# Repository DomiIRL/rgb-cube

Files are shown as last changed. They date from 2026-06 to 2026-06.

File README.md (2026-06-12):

# RGB Cube

A **6×6×6 RGB LED matrix cube** (216 WS2812B-compatible LEDs) that plays 3D
animations, driven by an ESP32. Firmware, 3D-printable parts, and build notes
all live in this repo.

> Built for the **"Rechnerarchitektur"** class at **Nordakademie**.

> [!WARNING]
> **The firmware is heavily "vibecoded."**
> Almost all of my time on this project went into the *physical* build —
> soldering 216 LEDs, printing jigs, bending legs, and wiring the cube took
> *really* long. To actually get animations running on the finished cube, the
> ESP32 code in [`code/`](code/) was written largely with AI assistance. It
> works on the real hardware, but don't read it as a model of clean,
> hand-crafted embedded C++.

## Hardware

| | |
|---|---|
| **LEDs** | 8 mm through-hole RGB, integrated WS2812B-compatible controller |
| **Grid** | 6 × 6 × 6 = 216 LEDs, 25 mm pitch, ~125 mm cube |
| **Wiring** | Single-wire WS2812B serpentine daisy-chain |
| **MCU** | ESP32 DevKit V1 (data on GPIO 14, mode button on GPIO 34) |
| **Power** | USB-C PD board (~5 A @ 5 V) |

Full geometry, electronics and enclosure specs: [`CLAUDE.md`](CLAUDE.md).

## Repository layout

```
rgb-cube/
├── code/      ESP32 firmware (PlatformIO)
├── models/    3D-printable parts (OpenSCAD sources + STLs + previews)
├── docs/      design notes (plans / specs)
├── BUILD.md   firmware build & dev guide
└── CLAUDE.md  hardware / geometry / model reference
```

## Firmware — [`code/`](code/)

PlatformIO project (`esp32dev` env, Arduino framework, Adafruit NeoPixel).
A hardware button cycles through animation modes; the active mode is persisted
in NVS across reboots.

**Build & flash** (easiest via the VSCode PlatformIO extension):

```bash
cd code
pio run -e esp32dev            # build
pio run -e esp32dev -t upload  # flash
```

See [`BUILD.md`](BUILD.md) for the Cube/Mode API and how to add a mode.

## 3D models — [`models/`](models/)

OpenSCAD sources with exported STLs and a render preview, one folder per part.
Printed on a Bambu Lab A1 Mini in PLA.

| Folder | Part |
|---|---|
| [`layer_jig/`](models/layer_jig/) | Soldering jig — holds one 6×6 LED layer flat while soldering |
| [`electronics_enclosure/`](models/electronics_enclosure/) | Base enclosure (body + lid) that hides the ESP32 and PD board; the cube sits on top |
| [`led_pin_bender/`](models/led_pin_bender/) | Tool to bend LED legs to a consistent shape |
| [`tests/`](models/tests/) | Throwaway calibration prints (LED hole fit, standoff fit) |

## Status

The cube is built and running animations. Open items (firmware tuning, final
wiring scheme) are tracked at the bottom of [`CLAUDE.md`](CLAUDE.md).

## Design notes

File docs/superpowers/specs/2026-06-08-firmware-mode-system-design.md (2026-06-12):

# Firmware Mode System — Design Spec
_2026-06-08_

## Goal

Provide a clean OOP firmware architecture for the 6×6×6 LED cube that:
- Addresses LEDs by (x, y, z) coordinates instead of raw index
- Supports multiple display modes, each encapsulated in its own class
- Allows mode switching via a button (hardcoded index for now, ISR later)

---

## Architecture

### Cube

Owns the `Adafruit_NeoPixel` strip. All LED writes go through it.

**Public API:**
- `begin()` — initialise strip
- `clear()` — zero all pixels
- `show()` — flush to hardware
- `setBrightness(uint8_t)`
- `setPixel(int x, int y, int z, uint8_t r, uint8_t g, uint8_t b)`
- `setPixel(int x, int y, int z, uint32_t color)`
- `static uint32_t colorRGB(uint8_t r, uint8_t g, uint8_t b)`
- `static uint32_t colorHSV(uint16_t hue, uint8_t sat, uint8_t val)`

**coordToIndex** is a private static method — single place to update when wiring scheme is finalised.  
Current mapping: `index = z * 36 + y * 6 + x` (layer-major, row-major, left-to-right).  
Out-of-bounds coordinates are silently ignored (return -1).

Constants `CUBE_SIZE = 6` and `CUBE_LEDS = 216` are defined in `Cube.h`.

---

### Mode (abstract base)

```cpp
class Mode {
public:
    virtual ~Mode() = default;
    virtual void update(Cube& cube, uint32_t ms) = 0;
    virtual void onEnter(Cube& cube) { cube.clear(); }
    virtual void onExit(Cube& cube) {}
};
```

`update()` is called every loop iteration. `ms` is `millis()` — modes use it for non-blocking animation timing. No `delay()` in any mode.

---

### ModeSolid

Sets all LEDs to a single color. Color is passed as a constructor argument.

```cpp
ModeSolid(uint8_t r, uint8_t g, uint8_t b);
```

`update()` only redraws on first call after `onEnter` to avoid redundant strip writes.

---

### main.cpp

```cpp
#define CURRENT_MODE 0   // change to switch mode; button will replace this

Mode* modes[] = { &modeSolid /*, &modeRainbow, ... */ };
constexpr int NUM_MODES = sizeof(modes) / sizeof(modes[0]);
int modeIndex = CURRENT_MODE;
```

Button ISR (future): increment `modeIndex % NUM_MODES`, call `modes[modeIndex-1]->onExit()`, call `modes[modeIndex]->onEnter()`.

---

## File Layout

```
src/
  main.cpp
  Cube.h
  Cube.cpp
  Mode.h
  modes/
    ModeSolid.h
    ModeSolid.cpp
```

Existing `test.cpp` cleared. `log.cpp` left empty.

---

## Constraints

- NEO_RGB color order (confirmed from hardware testing)
- Data pin: GPIO 4
- `coordToIndex` must be updated once wiring scheme is decided (CLAUDE.md: snake vs straight)
- Testing with 2 physical LEDs — code uses full 216-LED buffer; only first 2 respond

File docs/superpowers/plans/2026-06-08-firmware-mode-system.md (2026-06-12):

# Firmware Mode System Implementation Plan

> **For agentic workers:** REQUIRED SUB-SKILL: Use superpowers:subagent-driven-development (recommended) or superpowers:executing-plans to implement this plan task-by-task. Steps use checkbox (`- [ ]`) syntax for tracking.

**Goal:** Replace the ad-hoc test sketch with a clean OOP firmware: a `Cube` class for coordinate-based LED control, an abstract `Mode` base, and a `ModeSolid` mode — all wired together in `main.cpp` with a hardcoded mode selector ready for a button.

**Architecture:** `Cube` owns the `Adafruit_NeoPixel` strip and maps (x,y,z) → strip index through a single private method. `Mode` is a pure-virtual base; each mode class implements `update(Cube&, uint32_t ms)`. `main.cpp` holds a pointer array of modes and an index; switching a mode calls `onExit`/`onEnter` and re-points `currentMode`.

**Tech Stack:** ESP32 DevKit V1, PlatformIO + Arduino framework, Adafruit NeoPixel library, NEO_RGB color order, GPIO 4 data pin.

> **Note:** No unit test framework is available for embedded targets. Verification steps use `pio run` (compile check) and flash + serial monitor (behavioral check).

---

## File Map

| Action | Path | Responsibility |
|---|---|---|
| Create | `src/Cube.h` | Constants, Cube class declaration |
| Create | `src/Cube.cpp` | Cube implementation + coordToIndex |
| Create | `src/Mode.h` | Abstract Mode base class |
| Create | `src/modes/ModeSolid.h` | ModeSolid declaration |
| Create | `src/modes/ModeSolid.cpp` | ModeSolid implementation |
| Overwrite | `src/main.cpp` | Entry point, mode array, loop |
| Clear | `src/test.cpp` | Remove old test sketch (prevents duplicate setup/loop) |

---

### Task 1: Cube class

**Files:**
- Create: `src/Cube.h`
- Create: `src/Cube.cpp`

- [ ] **Step 1: Create `src/Cube.h`**

```cpp
#pragma once
#include <Adafruit_NeoPixel.h>

static constexpr uint8_t  CUBE_SIZE = 6;
static constexpr uint16_t CUBE_LEDS = CUBE_SIZE * CUBE_SIZE * CUBE_SIZE;

class Cube {
public:
    explicit Cube(uint8_t pin);
    void begin();
    void clear();
    void show();
    void setBrightness(uint8_t brightness);
    void setPixel(int x, int y, int z, uint8_t r, uint8_t g, uint8_t b);
    void setPixel(int x, int y, int z, uint32_t color);
    static uint32_t colorRGB(uint8_t r, uint8_t g, uint8_t b);
    static uint32_t colorHSV(uint16_t hue, uint8_t sat = 255, uint8_t val = 255);

private:
    Adafruit_NeoPixel _strip;
    static int coordToIndex(int x, int y, int z);
};
```

- [ ] **Step 2: Create `src/Cube.cpp`**

```cpp
#include "Cube.h"

Cube::Cube(uint8_t pin)
    : _strip(CUBE_LEDS, pin, NEO_RGB + NEO_KHZ800) {}

void Cube::begin()                    { _strip.begin(); _strip.show(); }
void Cube::clear()                    { _strip.clear(); }
void Cube::show()                     { _strip.show(); }
void Cube::setBrightness(uint8_t b)   { _strip.setBrightness(b); }

void Cube::setPixel(int x, int y, int z, uint8_t r, uint8_t g, uint8_t b) {
    int idx = coordToIndex(x, y, z);
    if (idx >= 0) _strip.setPixelColor(idx, r, g, b);
}

void Cube::setPixel(int x, int y, int z, uint32_t color) {
    int idx = coordToIndex(x, y, z);
    if (idx >= 0) _strip.setPixelColor(idx, color);
}

uint32_t Cube::colorRGB(uint8_t r, uint8_t g, uint8_t b) {
    return Adafruit_NeoPixel::Color(r, g, b);
}

uint32_t Cube::colorHSV(uint16_t hue, uint8_t sat, uint8_t val) {
    return Adafruit_NeoPixel::ColorHSV(hue, sat, val);
}

// TODO: update this mapping once wiring scheme is decided (snake vs straight)
// Current assumption: layer-major, row-major, left-to-right
// z=0 is bottom layer, x increases left-to-right, y increases front-to-back
int Cube::coordToIndex(int x, int y, int z) {
    if (x < 0 || x >= CUBE_SIZE ||
        y < 0 || y >= CUBE_SIZE ||
        z < 0 || z >= CUBE_SIZE) return -1;
    return z * CUBE_SIZE * CUBE_SIZE + y * CUBE_SIZE + x;
}
```

- [ ] **Step 3: Verify it compiles**

```bash
cd ~/projects/led-cube/code && pio run
```

Expected: `[SUCCESS]` — the Cube files compile but nothing calls them yet (no linker errors since main still exists from test.cpp).

---

### Task 2: Mode base class

**Files:**
- Create: `src/Mode.h`

- [ ] **Step 1: Create `src/Mode.h`**

```cpp
#pragma once
#include "Cube.h"

class Mode {
public:
    virtual ~Mode() = default;
    virtual void update(Cube& cube, uint32_t ms) = 0;
    virtual void onEnter(Cube& cube) { cube.clear(); cube.show(); }
    virtual void onExit(Cube& cube)  {}
};
```

- [ ] **Step 2: Verify it compiles**

```bash
pio run
```

Expected: `[SUCCESS]`

---

### Task 3: ModeSolid

**Files:**
- Create: `src/modes/ModeSolid.h`
- Create: `src/modes/ModeSolid.cpp`

- [ ] **Step 1: Create `src/modes/ModeSolid.h`**

```cpp
#pragma once
#include "../Mode.h"

class ModeSolid : public Mode {
public:
    ModeSolid(uint8_t r, uint8_t g, uint8_t b);
    void update(Cube& cube, uint32_t ms) override;
    void onEnter(Cube& cube) override;

private:
    uint8_t _r, _g, _b;
    bool _drawn;
};
```

- [ ] **Step 2: Create `src/modes/ModeSolid.cpp`**

```cpp
#include "ModeSolid.h"

ModeSolid::ModeSolid(uint8_t r, uint8_t g, uint8_t b)
    : _r(r), _g(g), _b(b), _drawn(false) {}

void ModeSolid::onEnter(Cube& cube) {
    _drawn = false;
    cube.clear();
    cube.show();
}

void ModeSolid::update(Cube& cube, uint32_t ms) {
    if (_drawn) return;
    for (int z = 0; z < CUBE_SIZE; z++)
        for (int y = 0; y < CUBE_SIZE; y++)
            for (int x = 0; x < CUBE_SIZE; x++)
                cube.setPixel(x, y, z, _r, _g, _b);
    cube.show();
    _drawn = true;
}
```

- [ ] **Step 3: Verify it compiles**

```bash
pio run
```

Expected: `[SUCCESS]`

---

### Task 4: Wire up main.cpp

**Files:**
- Overwrite: `src/main.cpp` (create if absent)
- Clear: `src/test.cpp` (must be empty to avoid duplicate `setup`/`loop` linker error)

- [ ] **Step 1: Clear `src/test.cpp`**

Replace the entire content of `src/test.cpp` with an empty file (zero bytes).

- [ ] **Step 2: Write `src/main.cpp`**

```cpp
#include <Arduino.h>
#include "Cube.h"
#include "modes/ModeSolid.h"

#define DATA_PIN     4
#define CURRENT_MODE 0   // 0 = solid red; button will replace this

Cube cube(DATA_PIN);

ModeSolid modeSolid(255, 0, 0);   // red

Mode* modes[] = { &modeSolid };
constexpr int NUM_MODES = sizeof(modes) / sizeof(modes[0]);

int       modeIndex   = CURRENT_MODE;
Mode*     currentMode = modes[CURRENT_MODE];

void setMode(int index) {
    currentMode->onExit(cube);
    modeIndex   = index % NUM_MODES;
    currentMode = modes[modeIndex];
    currentMode->onEnter(cube);
}

void setup() {
    Serial.begin(115200);
    Serial.println("LED Cube boot OK");
    cube.begin();
    cube.setBrightness(50);
    currentMode->onEnter(cube);
}

void loop() {
    currentMode->update(cube, millis());
}
```

- [ ] **Step 3: Build**

```bash
pio run
```

Expected: `[SUCCESS]` with RAM ~6%, Flash ~21%.

- [ ] **Step 4: Flash and verify**

```bash
pio run --target upload && pio device monitor
```

Expected serial output:
```
LED Cube boot OK
```
Expected hardware: LED(s) solid red, not blinking.

---

## Adding more modes later

To add a new mode (e.g. `ModeRainbow`):

1. Create `src/modes/ModeRainbow.h` and `src/modes/ModeRainbow.cpp` following the same pattern as `ModeSolid`.
2. In `main.cpp`: `#include "modes/ModeRainbow.h"`, instantiate `ModeRainbow modeRainbow;`, add `&modeRainbow` to the `modes[]` array.
3. To switch via button: call `setMode((modeIndex + 1) % NUM_MODES)` in the button ISR.

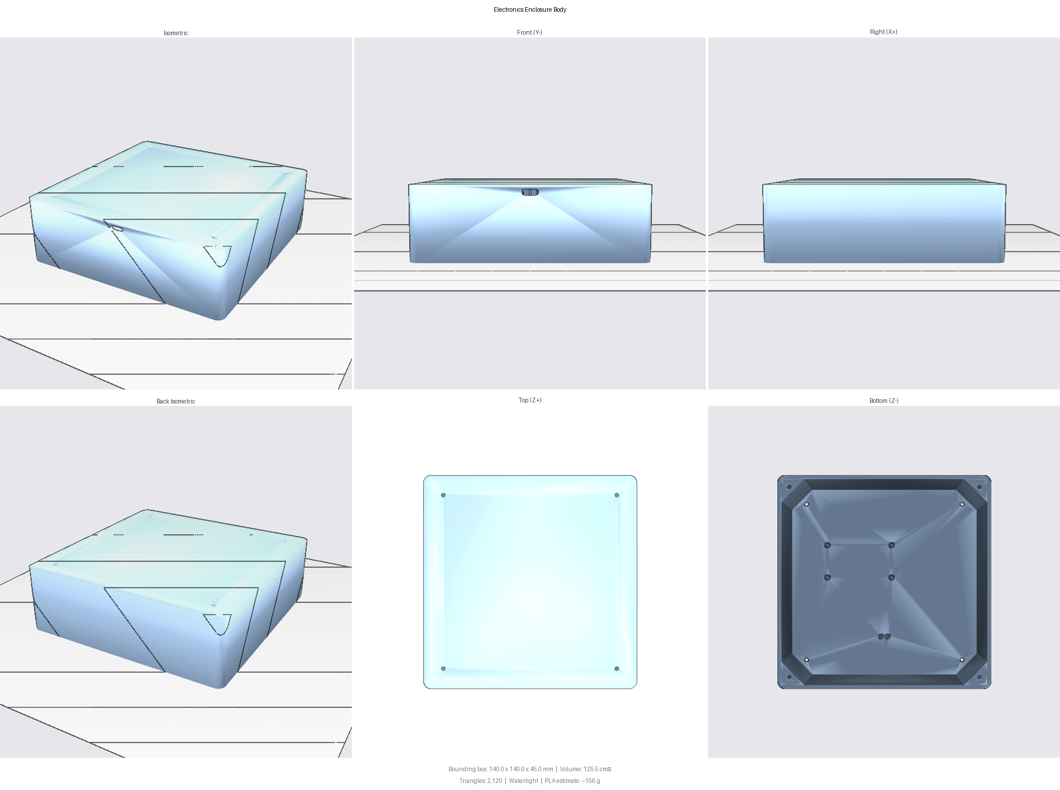
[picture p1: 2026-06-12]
models/electronics_enclosure/electronics_enclosure_body_preview.png

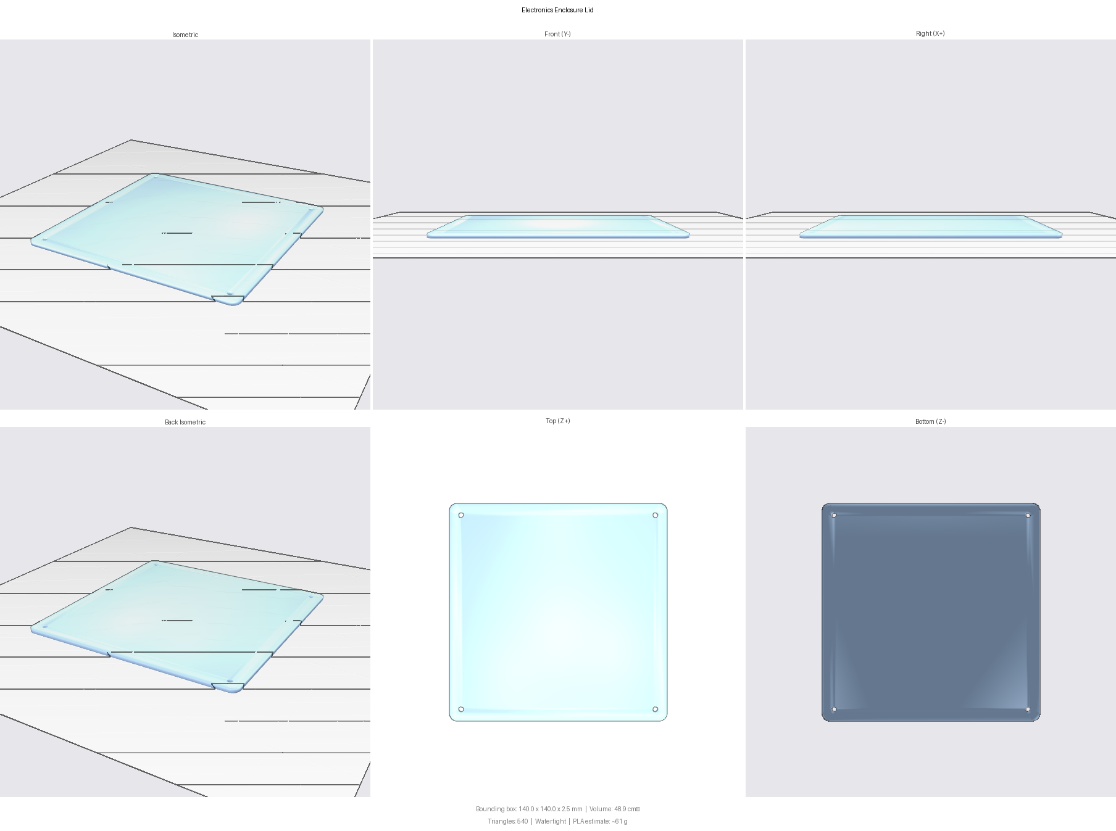
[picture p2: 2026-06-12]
models/electronics_enclosure/electronics_enclosure_lid_preview.png

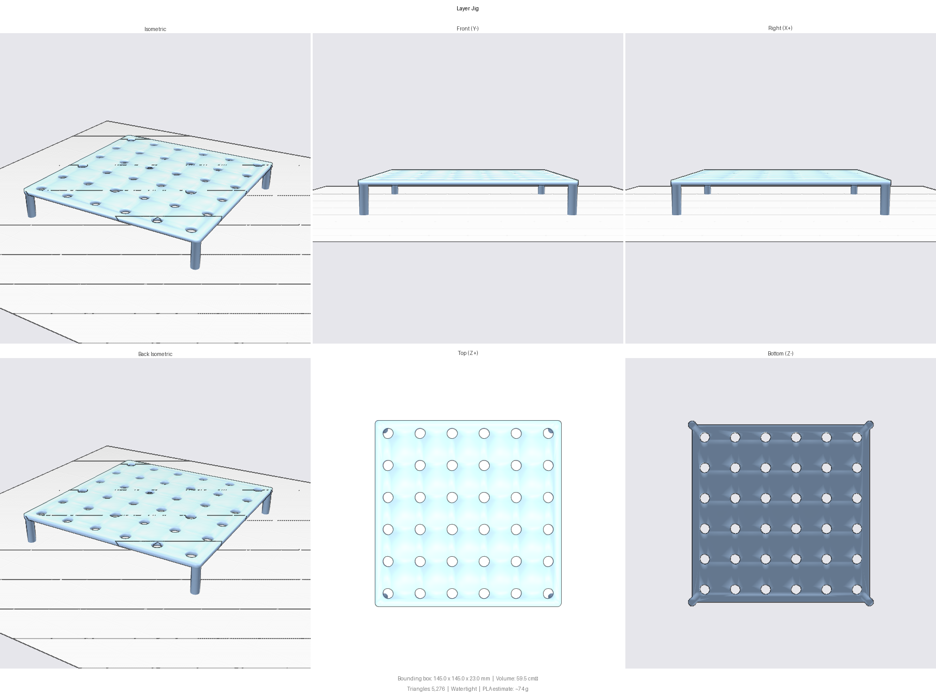
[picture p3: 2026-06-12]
models/layer_jig/layer_jig_preview.png

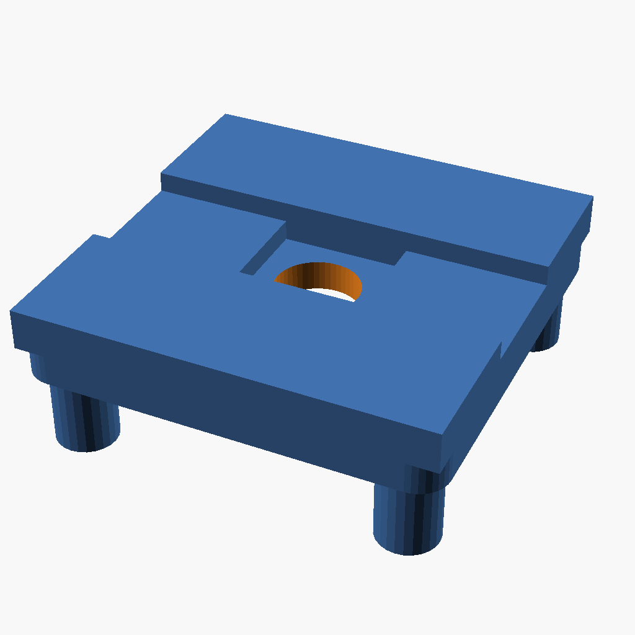
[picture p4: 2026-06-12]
models/led_pin_bender/led_pin_bender_preview.png

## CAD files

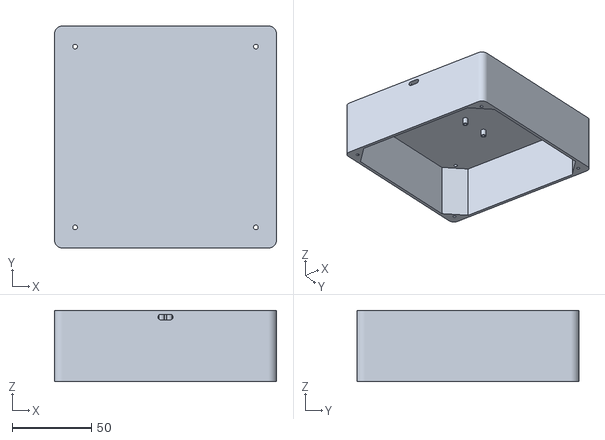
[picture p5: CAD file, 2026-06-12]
models/electronics_enclosure/electronics_enclosure_body.stl
140.0 x 140.0 x 45.0

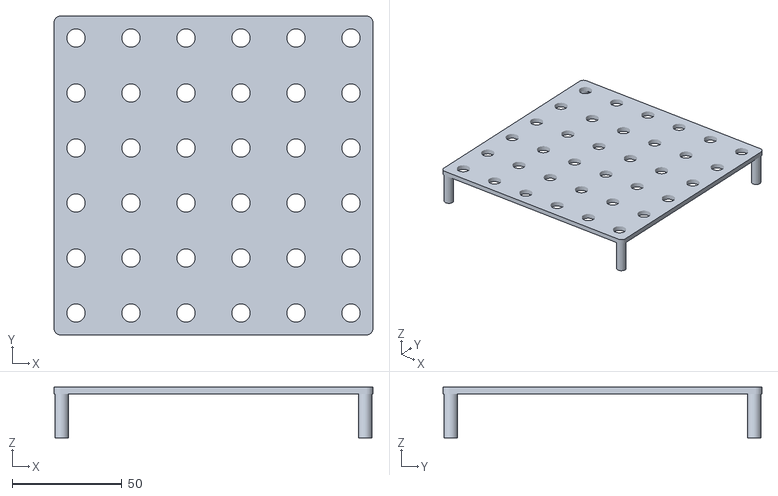
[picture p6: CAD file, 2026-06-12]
models/layer_jig/layer_jig.stl
145.0 x 145.0 x 23.0

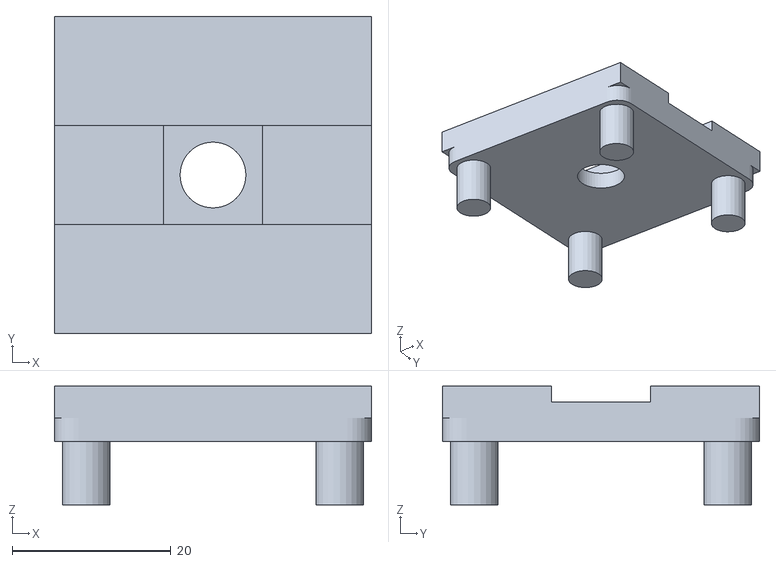
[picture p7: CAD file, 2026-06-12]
models/led_pin_bender/led_pin_bender.stl
40.0 x 40.0 x 15.0

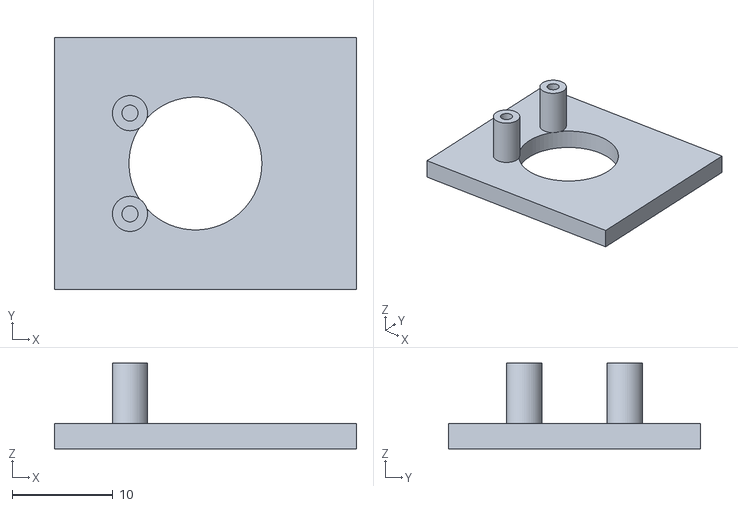
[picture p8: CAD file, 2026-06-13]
models/tests/ir_receiver_mount_test.stl
30.0 x 25.0 x 8.50

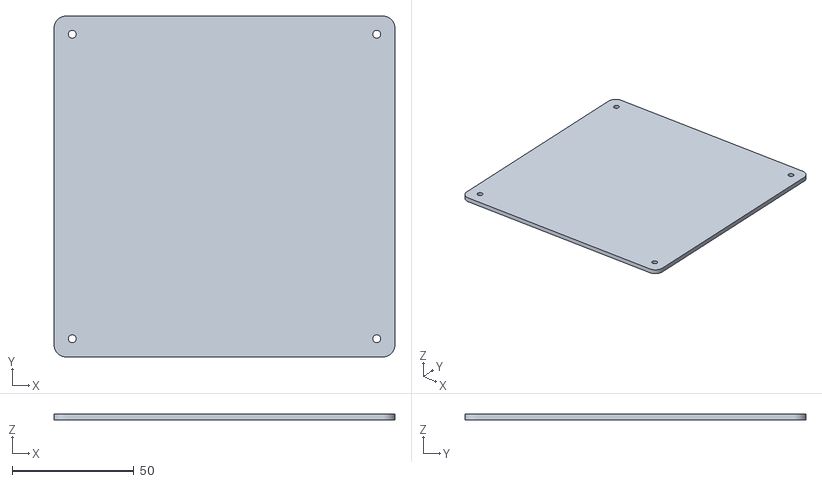
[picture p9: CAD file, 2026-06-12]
models/electronics_enclosure/electronics_enclosure_lid.stl
140.0 x 140.0 x 2.50

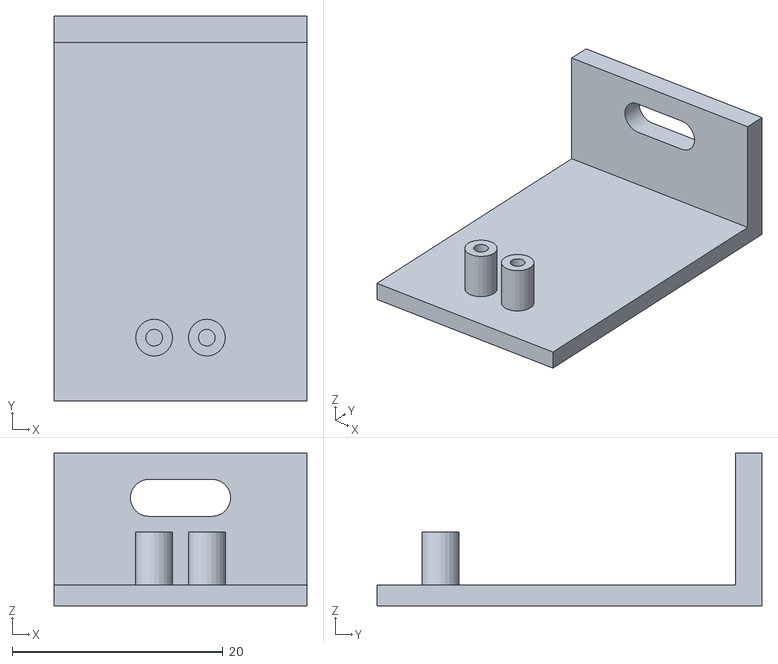
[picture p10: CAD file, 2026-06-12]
models/tests/usbc_mount_test.stl
24.0 x 36.5 x 14.5

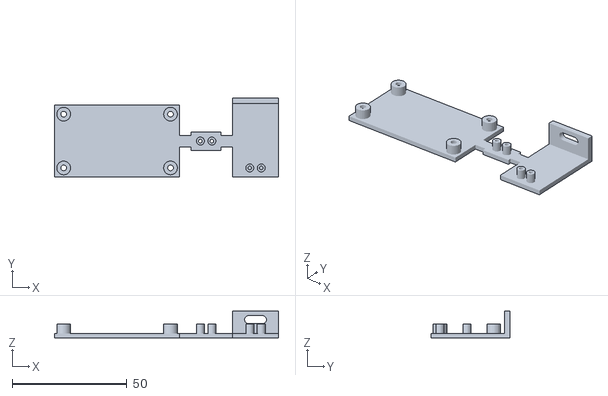
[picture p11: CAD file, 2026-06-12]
models/tests/standoff_test.stl
97.5 x 34.5 x 11.8

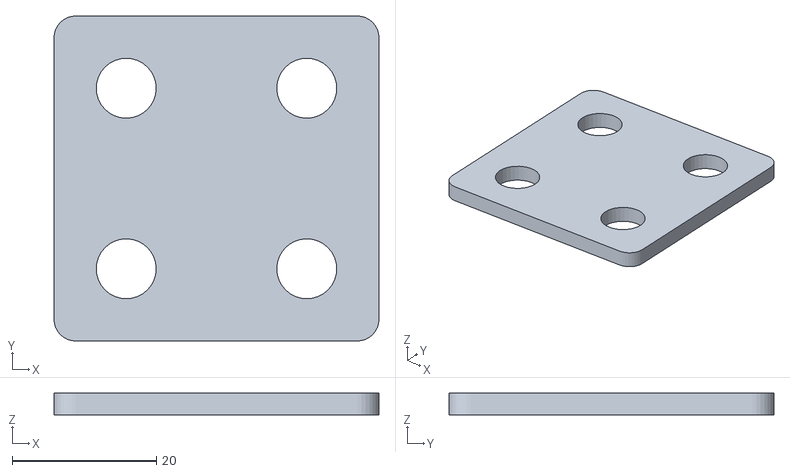
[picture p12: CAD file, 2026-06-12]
models/tests/led_hole_test.stl
45.0 x 45.0 x 3.00

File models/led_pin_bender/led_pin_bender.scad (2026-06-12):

// ============================================================
// LED Pin Bending Jig — single 8mm through-hole RGB LED
//
// Usage: insert LED lens-first from above (pins pointing UP).
// The collar/flange rests on the flat board top surface.
// The dome hangs below the board in the leg clearance.
// Bend pins outward against the elevated tabs.
//
// Printer: Bambu Lab A1 Mini
// Print orientation: legs down on bed (same as layer_jig)
// ============================================================

// ============================================================
// PARAMETERS
// ============================================================

// LED body
led_body_d    = 8.0;   // mm — LED cylinder / dome diameter
led_clearance = 0.3;   // mm — hole oversize for smooth insertion
collar_d      = 9.5;   // mm — collar/flange diameter (MEASURE YOUR LED!)
                        //      Must be > hole_d (8.3) or LED will fall through.

// Board (flat plate — same style as layer_jig)
board_w  = 40.0;   // mm — board width  (X)
board_l  = 40.0;   // mm — board length (Y)
board_t  = 3.0;    // mm — board thickness
corner_r = 3.0;    // mm — outer corner radius

// Legs — elevate board to clear the inverted LED dome (~4mm radius)
leg_h = 8.0;   // mm — leg height (> LED dome radius; 8mm gives 4mm margin)
leg_d = 6.0;   // mm — leg diameter

// Bending tabs — one per side, inner face clears the LED collar
tab_gap    = 1.5;   // mm — gap between collar edge and inner tab face
tab_w      = 5.0;   // mm — tab span (perpendicular to outward direction)
tab_l      = 4.0;   // mm — tab depth (outward from hole centre)
tab_h_low  = 2.0;   // mm — height above board top on ±X sides
tab_h_high = 4.0;   // mm — height above board top on ±Y sides

// ============================================================
// DERIVED
// ============================================================
hole_d     = led_body_d + led_clearance;    // 8.3 mm
tab_offset = collar_d / 2 + tab_gap;        // inner face of tab from centre
leg_pos    = board_w / 2 - leg_d / 2 - 1;  // leg centre (inset from corners)
board_z    = leg_h;                          // Z of board bottom face
eps        = 0.01;

// ============================================================
// MODULES
// ============================================================

// One bending wall — runs from tab_offset to the board edge,
// spanning the full board width in the perpendicular direction.
// Rotated into place for each of the four sides.
module bend_tab(h) {
    wall_len = board_w / 2 - tab_offset;   // inner face → board edge
    translate([tab_offset, -board_l / 2, board_z + board_t])
    cube([wall_len, board_l, h]);
}

// ============================================================
// MODEL  —  Z=0 on print bed, board top at Z = leg_h + board_t
// ============================================================

// --- Corner legs (same pattern as layer_jig) ---
for (sx = [-1, 1]) for (sy = [-1, 1]) {
    translate([sx * leg_pos, sy * leg_pos, 0])
    cylinder(d=leg_d, h=leg_h + eps, $fn=24);
}

// --- Board (flat plate elevated on legs) ---
translate([0, 0, board_z])
difference() {
    // Rounded-corner board (minkowski of box + flat cylinder)
    translate([0, 0, board_t / 2])
    minkowski() {
        cube([board_w - 2*corner_r,
              board_l - 2*corner_r,
              board_t - 0.001], center=true);
        cylinder(r=corner_r, h=0.001, $fn=32);
    }

    // LED body through-hole — collar rests on flat top surface,
    // dome hangs below into leg clearance
    translate([0, 0, -eps])
    cylinder(d=hole_d, h=board_t + 2*eps, $fn=48);
}

// --- Bending tabs on board top ---
// Two opposing sides at tab_h_low (2 mm): ±X
for (a = [0, 180]) rotate([0, 0, a]) bend_tab(tab_h_low);

// Two opposing sides at tab_h_high (4 mm): ±Y
for (a = [90, 270]) rotate([0, 0, a]) bend_tab(tab_h_high);

// ============================================================
// KEY DIMENSIONS
// board          : 40 × 40 × 3 mm   (bottom at z=8, top at z=11)
// legs           : ⌀6 mm, 8 mm tall — 4 mm dome clearance below board
// hole_d         : 8.3 mm   (8.0 + 0.3 clearance)
// collar_d       : 9.5 mm   (MEASURE AND ADJUST — must be > 8.3 mm)
// tab inner face : 6.25 mm from centre   (collar edge + 1.5 mm gap)
// low tabs  (±X) : 2 mm above board top
// high tabs (±Y) : 4 mm above board top
// ============================================================

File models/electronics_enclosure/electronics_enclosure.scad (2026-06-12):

// ============================================================
// LED Cube Electronics Enclosure
// Houses: ESP32 DevKit V1 + USB-C PD power board
// Cube (6×6×6, 25mm pitch, 125×125mm footprint) rests on top
// Open bottom faces DOWN; lid screws onto bottom rim (4× M3)
// Printer: Bambu Lab A1 Mini (180×180mm bed)
// Print orientation: SOLID TOP FACE DOWN ON BED
// ============================================================

// ============================================================
// PARAMETERS
// ============================================================

part = "body";  // "body" or "lid"

// Outer shell
width    = 140.0;  // mm — 125mm cube footprint + ~7.5mm margin each side
depth    = 140.0;  // mm
height   =  45.0;  // mm
wall     =   2.5;  // mm
floor_t  =   2.5;  // mm — solid top plate
corner_r =   5.0;  // mm — outer corner radius

// 4 corner fixation holes in top plate
// Thread a short wire through each hole + around a corner LED lead to tie cube down.
fix_hole_d = 3.0;   // mm
fix_corner = 57.0;  // mm — slightly inward from cube corner (62.5mm) to stay clear of corner fills

// 45° corner fills — solid triangular prisms in each inner cavity corner.
// Much stronger than cylinders: the fill bonds to both adjacent walls and
// the ceiling, and the M3 screw threads directly into the solid PLA mass.
corner_fill = 15.0; // mm — leg length of the right-angle triangle (per side)

// M3 lid screws — pilot hole into the corner fill (self-tap in PLA)
lid_screw_pilot = 2.5;   // mm — M3 pilot: screw cuts thread into PLA
lid_screw_clear = 3.3;   // mm — M3 clearance in lid plate
lid_screw_depth = 12.0;  // mm — pilot depth (more = better thread engagement)

// USB-C port cutout — back face (−Y), stadium profile (r = h/2)
usbc_w  =  9.5;  // mm — port opening width
usbc_h  =  3.5;  // mm — port opening height (USB-C connector ~2.56 mm + tolerance)
// Measured on the real board (dry-fit): the TOP of the USB-C port sits this far
// above the PCB's reference (bottom) face, which seats on the standoffs at board_z.
usbc_port_top_above_board = 5.0;  // mm — measured top-of-port above PCB bottom

// ESP32 DevKit V1 standoffs — centred at (+18, +15), clear of corners
// Board: 51.5×28.6mm, 4× M3 holes ⌀3mm at 46.5×23.4mm spacing (source: mischianti.org)
esp_ox  =  18.0;  // mm — pattern centre offset X
esp_oy  =  15.0;  // mm — pattern centre offset Y
esp_mx  =  46.5;  // mm — mounting hole spacing X (DevKit V1, long axis)
esp_my  =  23.4;  // mm — mounting hole spacing Y (DevKit V1, short axis)
esp_od  =   4.0;  // mm — standoff outer diameter (slim to clear PCB components when upside-down)
esp_h   =   5.0;  // mm — standoff height
esp_sd  =   2.5;  // mm — M3 self-tap pilot in PLA (board holes are ⌀3mm → M3 screws)

// USB-C PD board standoffs — same height as ESP32, near back face
// Measured: hole ⌀2 mm, c-c spacing 5 mm, hole centre 28 mm from PCB edge,
// connector protrudes 1 mm past PCB edge (tip is 29 mm from hole centres).
// Board PCB edge flush with inner wall (Y=−67.5 mm) → hole centres at Y=−39.5 mm.
usbc_bmx =   5.0;  // mm — mounting hole spacing X (measured)
usbc_boy = -39.5;  // mm — board centre Y (hole centres, 28 mm from PCB back edge)
usbc_bod =   3.5;  // mm — standoff outer ⌀ (must be < 5 mm c-c spacing)
usbc_bsd =   1.6;  // mm — M2 self-tap pilot in PLA (board holes ⌀2 mm → M2 screws)

// Lid
lid_t = 2.5;  // mm

// ============================================================
// DERIVED
// ============================================================
inner_w = width  - 2*wall;   // 125 mm
inner_d = depth  - 2*wall;   // 125 mm
inner_h = height - floor_t;  // 42.5 mm
ceil_z  = height - floor_t;  // 42.5 mm

// Both boards hang from ceiling on standoffs of height esp_h
board_z = ceil_z - esp_h;    // 37.5 mm — PCB surface height from Z=0
// USB-C port centre: derive from the measured top-of-port, then drop half the
// opening height. board_z(37.5) + 5.0 − 1.75 = 40.75 mm; top of opening = 42.5 mm
// (flush with the inner ceiling — port sits as high as the cavity allows).
usbc_z  = board_z + usbc_port_top_above_board - usbc_h/2;  // 40.75 mm

// Corner fill screw hole: at the centroid of each triangular fill
// centroid is corner_fill/3 inward from each wall face
screw_cx = inner_w/2 - corner_fill/3;   // ≈ 55.8 mm from centre
screw_cy = inner_d/2 - corner_fill/3;

eps = 0.01;

// ============================================================
// MODULE: USB-C stadium profile (2D, XY plane, centred at origin)
// ============================================================
module usbc_stadium() {
    r = usbc_h / 2;
    hull() {
        translate([-(usbc_w/2 - r), 0]) circle(r=r, $fn=32);
        translate([ (usbc_w/2 - r), 0]) circle(r=r, $fn=32);
    }
}

// ============================================================
// MODULE: one 45° corner fill + screw pilot hole
// sx/sy: sign for which corner (+1 or −1)
// ============================================================
module corner_block(sx, sy) {
    // Absolute inner corner position
    cx = sx * inner_w/2;
    cy = sy * inner_d/2;

    // Screw hole centre
    hx = sx * screw_cx;
    hy = sy * screw_cy;

    difference() {
        // Triangular prism filling the 45° corner — full height so it bonds
        // to both adjacent walls AND the ceiling.
        linear_extrude(height = ceil_z + eps)
        polygon([
            [cx,              cy             ],   // inner corner point
            [cx - sx*corner_fill, cy        ],   // along X wall
            [cx,              cy - sy*corner_fill]    // along Y wall
        ]);

        // M3 pilot hole from open bottom (Z=0) — screw threads into PLA
        translate([hx, hy, -eps])
        cylinder(d=lid_screw_pilot, h=lid_screw_depth + eps*2, $fn=20);
    }
}

// ============================================================
// BODY
// ============================================================
if (part == "body") {

    difference() {
        // ---- Outer solid box ----
        translate([0, 0, height/2])
        minkowski() {
            cube([width  - 2*corner_r,
                  depth  - 2*corner_r,
                  height - eps], center=true);
            cylinder(r=corner_r, h=eps, $fn=48);
        }

        // ---- Hollow interior (open bottom to ceiling) ----
        translate([-inner_w/2, -inner_d/2, -eps])
        cube([inner_w, inner_d, inner_h + eps]);

        // ---- 4 corner fixation holes in top plate ----
        for (sx = [-1, 1]) for (sy = [-1, 1]) {
            translate([sx * fix_corner, sy * fix_corner, ceil_z - eps])
            cylinder(d=fix_hole_d, h=floor_t + eps*2, $fn=20);
        }

        // ---- USB-C port cutout (back face = −Y) — stadium profile ----
        translate([0, -(depth/2) - eps, usbc_z])
        rotate([-90, 0, 0])
        linear_extrude(height = wall + 2*eps)
            usbc_stadium();
    }

    // ---- 45° corner fills with M3 pilot holes ----
    for (sx = [-1, 1]) for (sy = [-1, 1]) {
        corner_block(sx, sy);
    }

    // ---- ESP32 standoffs (hang from ceiling) ----
    for (sx = [-1, 1]) for (sy = [-1, 1]) {
        px = sx * esp_mx/2 + esp_ox;
        py = sy * esp_my/2 + esp_oy;
        difference() {
            translate([px, py, ceil_z - esp_h])
            cylinder(d=esp_od, h=esp_h + eps, $fn=24);
            translate([px, py, ceil_z - esp_h - eps])
            cylinder(d=esp_sd, h=esp_h + eps*3, $fn=20);
        }
    }

    // ---- USB-C PD board standoffs (same height as ESP32) ----
    for (sx = [-1, 1]) {
        px = sx * usbc_bmx / 2;
        py = usbc_boy;
        difference() {
            translate([px, py, ceil_z - esp_h])
            cylinder(d=usbc_bod, h=esp_h + eps, $fn=24);
            translate([px, py, ceil_z - esp_h - eps])
            cylinder(d=usbc_bsd, h=esp_h + eps*3, $fn=20);
        }
    }
}

// ============================================================
// LID — flat plate with 4× M3 clearance holes at corner centroids
// ============================================================
if (part == "lid") {
    difference() {
        translate([0, 0, lid_t/2])
        minkowski() {
            cube([width  - 2*corner_r,
                  depth  - 2*corner_r,
                  lid_t - eps], center=true);
            cylinder(r=corner_r, h=eps, $fn=48);
        }
        for (sx = [-1, 1]) for (sy = [-1, 1]) {
            translate([sx * screw_cx, sy * screw_cy, -eps])
            cylinder(d=lid_screw_clear, h=lid_t + eps*2, $fn=20);
        }
    }
}
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

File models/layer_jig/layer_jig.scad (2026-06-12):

// ============================================================
// LED Cube Assembly Jig — one layer (6×6 grid)
// 8mm through-hole RGB LEDs with integrated controller
// Printer: Bambu Lab A1 Mini (180×180mm bed)
// Print orientation: legs down on bed
// ============================================================

// ============================================================
// PARAMETERS
// ============================================================

// LED (8mm body)
led_body_d    = 8.0;   // mm — LED body diameter
led_clearance = 0.3;   // mm — hole oversize for easy insertion/removal

// Grid
grid_n        = 6;     // LEDs per side (6×6 layer)
pitch         = 25.0;  // mm — center-to-center spacing
                       // 25 mm → 17 mm gap between 8 mm LED bodies;
                       // comfortable room for soldering iron + wire

// Board
margin        = 10.0;  // mm — board edge beyond outermost LED centers
board_t       = 3.0;   // mm — board thickness
corner_r      = 3.0;   // mm — corner rounding radius

// Legs — elevate board so LED leads (≤15 mm) hang freely below
leg_d         = 6.0;   // mm — leg diameter
leg_h         = 20.0;  // mm — leg height (longer than 15 mm DO lead)

// ============================================================
// DERIVED
// ============================================================
hole_d      = led_body_d + led_clearance;            // 8.3 mm
board_side  = (grid_n - 1) * pitch + 2 * margin;    // 145 mm
grid_start  = -(grid_n - 1) * pitch / 2;            // −62.5 mm — centre the grid
leg_pos     = board_side / 2 - leg_d / 2 - 0.5;    // 69 mm — just inside board corners
                                                      // (2 mm clear of corner LED holes)

// ============================================================
// MODEL
// ============================================================

// Board — raised on legs so LED leads hang freely in the gap below
translate([0, 0, leg_h])
difference() {
    // Rounded-corner board (minkowski of box + cylinder)
    translate([0, 0, board_t / 2])
    minkowski() {
        cube([board_side - 2*corner_r,
              board_side - 2*corner_r,
              board_t - 0.001], center=true);
        cylinder(r=corner_r, h=0.001, $fn=32);
    }

    // 6×6 grid of LED body holes (through the full board thickness)
    for (row = [0 : grid_n - 1]) {
        for (col = [0 : grid_n - 1]) {
            translate([grid_start + col * pitch,
                       grid_start + row * pitch,
                       -0.01])
            cylinder(d=hole_d, h=board_t + 0.02, $fn=32);
        }
    }
}

// Corner legs (slightly overlap board bottom for a clean union)
for (sx = [-1, 1]) for (sy = [-1, 1]) {
    translate([sx * leg_pos, sy * leg_pos, 0])
    cylinder(d=leg_d, h=leg_h + 0.01, $fn=24);
}

// ============================================================
// KEY DIMENSIONS
// total height   : 23 mm (20 mm legs + 3 mm board)
// board          : 145 × 145 × 3 mm (elevated at z = 20 mm)
// hole_d         : 8.3 mm  (8.0 mm LED + 0.3 mm clearance)
// pitch          : 25 mm   (17 mm gap between LED bodies)
// grid           : 6×6 = 36 LEDs per layer
// legs           : ⌀6 mm, 20 mm tall, centres at ±69 mm
// lead clearance : 20 mm > 15 mm (longest DO lead) ✓
// ============================================================

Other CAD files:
models/tests/ir_receiver_mount_test.scad
models/tests/led_hole_test.scad
models/tests/standoff_test.scad
models/tests/usbc_mount_test.scad

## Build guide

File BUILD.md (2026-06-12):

# BUILD — LED Cube firmware dev guide

Concise build/dev reference so a session can work without re-reading all of `code/src/`.
Hardware, geometry, enclosure and 3D-model specs live in **`CLAUDE.md`** — not repeated here.

## Build & flash
- **Source of truth = the user's VSCode + PlatformIO extension.** Build and flash from there.
- CLI equivalent (only if the shell env is already set up): from `code/` run
  `pio run -e esp32dev` and `pio run -e esp32dev -t upload`.
- **Do NOT touch / "repair" the Python or PlatformIO venv.** If `~/.platformio/penv/bin/pio`
  fails in the agent shell with `ModuleNotFoundError: No module named 'platformio'`, that is a
  shell-environment mismatch, **not** a broken venv — it builds fine in the user's VSCode.
  Never rebuild the venv or switch Python versions; doing so breaks the working setup.
- No-hardware sanity check: compile a mode header with host `g++ -std=gnu++17 -fsyntax-only`
  against tiny stub `Arduino.h` / `Adafruit_NeoPixel.h`. Catches C++ errors — but **not**
  Arduino-macro collisions (see Gotchas), so stub the relevant macros if you rely on this.

## Layout (`code/`)
- `platformio.ini` — env `esp32dev`, framework `arduino`, deps `Adafruit NeoPixel`, `IRremote`.
- `src/main.cpp` — pins (DATA=14, control button=33, BOOT=0, IR receiver=34), the `modes[]`
  registry, BOOT-button + IR-remote control, brightness/speed/pause/blank/auto-cycle state, and
  NVS persistence of all of them (`saveSettings()` writes mode+bright+speed+paused+display+cycle;
  `setup()` restores them). `handleIrCommand()` maps the full Elegoo NEC remote: ▲/▼ next/prev
  mode, number keys (multi-digit, "1"+"0" = mode 10), `>>|`/`|<<` faster/slower, VOL+/- brightness,
  EQ factory reset (wipes NVS → defaults), `>||` pause, Power blank, FUNC/STOP restart, ST/REPT
  auto-cycle (cancelled by any manual mode change). Modes run on a speed-scaled virtual clock
  (`modeClock`), NOT real `millis()` — so speed/pause are global with no per-mode changes. Every
  decoded frame is logged via `printIRResultShort` for remapping. Power the receiver at
  **3.3 V** (see CLAUDE.md). All IR protocol decoders are enabled (no `#define DECODE_NEC`).
- `src/Cube.{h,cpp}` — LED buffer + drawing API. **No software power cap** (removed — the cube
  runs off the USB-C PD board, not the ESP32 diode). Global brightness in `main.cpp`
  (`BRIGHT_MAX` ≈ 80) is the only guard keeping a full-white frame under the ~5 A PD rating.
- `src/Mode.h` — `Mode` base class.
- `src/modes/Mode*.h` — one header-only mode per file.
- `src/Text.{h,cpp}` — scrolling text used for mode labels.

## Cube / Mode API (what a mode needs)
- Geometry: `CUBE_X/Y/Z = 6`, `CUBE_LEDS = 216`. **Y is up** — gravity is −Y, floor `y=0`,
  top `y=5`.
- `class Mode`: override `void update(Cube&, uint32_t ms)`; optional `onEnter/onExit`.
  Gate timing on `ms - _last >= stepMs`, repaint the frame, then call `cube.show()`. **`ms` is a
  speed-scaled virtual clock (`main.cpp::modeClock`), not real `millis()`** — gate only on the
  passed `ms` (never call `millis()` inside a mode) so the remote's speed/pause controls work.
- `Cube`: `setPixel(x,y,z,color)` (serpentine wiring is handled inside — always go through
  this, never index the strip directly), `setPixel(index,color)`, `clear()`, `show()`,
  `setBrightness(v)`. Colours: `Cube::colorRGB(r,g,b)` / `Cube::colorHSV(h,s,v)`, both packed
  as `(r<<16)|(g<<8)|b`.

## Add a new mode
1. Create `src/modes/ModeX.h`: `#pragma once`, `#include "../Mode.h"`, subclass `Mode`.
2. In `main.cpp`: add `#include "modes/ModeX.h"`, a global `ModeX modeX;`, and `&modeX` in
   the `modes[]` array.
3. `INITIAL_MODE` indexes `modes[]`; the active mode is also persisted in NVS across reboots.

## Gotchas
- **Arduino predefines macros that silently clobber bare identifiers** — notably `FALLING`,
  `RISING`, `CHANGE`, `HIGH`, `LOW`, `INPUT`, `OUTPUT`, `min`, `max`, `abs`. Never use these as
  enum constants or variable names. (A bare `FALLING` enumerator once broke the Tetris-mode
  build — fixed by prefixing the phase enum `PH_*`.) A host `g++` check with a bare stub
  `Arduino.h` will NOT catch this; define the colliding macros in the stub to reproduce it.
- **`<IRremote.hpp>` carries its own implementation — include it in exactly ONE translation
  unit** (currently `main.cpp`). Including it from a second `.cpp` causes multiple-definition
  link errors. `#define DECODE_NEC` before the include keeps it lean (NEC-only).

## Keep this file in sync
A `SessionStart` hook (`.claude/settings.json`) points every session here. Whenever you change
build/flash steps, the layout, the Cube/Mode API, add a mode, or learn a new gotcha,
**mirror that change into this file in the same turn** so it never goes stale.

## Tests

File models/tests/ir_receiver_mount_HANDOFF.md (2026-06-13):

# IR Receiver Mount — Handoff

**Status:** v5 (screw-mount via the board's 2 mounting holes) generated, **awaiting print + fit feedback from user.**
**Last updated:** 2026-06-13
**Files:** `ir_receiver_mount_test.scad` / `.stl` / `_preview.png` (this folder)

---

## Goal

Mount an **Elegoo IR receiver board** (TSOP-1838, NEC remote) inside the LED-cube
electronics enclosure so the sensor **head pokes UP through the top plate into the
air gap between four LEDs** (the cube is an open lattice — ~70% air — so the dome
hides among the LEDs). Firmware side is already noted in `CLAUDE.md`
(signal → GPIO34, VCC → 3.3 V, NEC).

The files in this folder are a **minimal fit-test piece**, not the final part — a
small patch of the top plate + the mount, printed standalone so the user can
validate fit before it's grafted into `electronics_enclosure.scad`.

---

## Measured board

| Property | Value | Source |
|---|---|---|
| PCB length | 20 mm (X) | 2026-06-12 |
| PCB width | 15 mm (Y) | 2026-06-12 |
| PCB thickness | 1.0 mm | 2026-06-12 |
| Head (dome) diameter | 12 mm | 2026-06-12 |
| Head height above PCB face | 10 mm | 2026-06-12 |
| Head position (along length) | **closer to the NO-PIN edge** (≈9 mm from it) → `head_cx = −1` | user 2026-06-13 |
| Head position (across width) | centred (y = 0) | 2026-06-12 |
| Pins | 3-pin header, **same face as the head**, 5 mm tall, overhanging the **other** short (15 mm) edge by 4 mm | 2026-06-12 |
| **Mounting holes** | **2 ×, ⌀2.0 mm, 10 mm apart (centre-centre), 2.5 mm from the NO-PIN edge (centre→edge), centred on width (y = ±5)** | **user 2026-06-13** |

The two mounting holes are on the **no-pin** short edge — the same end the head
sits closest to. So at that end the head and the two holes are crowded together
(see the head↔standoff note below). Pins/wires hang off the **opposite** edge.

---

## Design evolution

- **v1** — round dome hole + drop-in pocket with snap-lips. Guessed dims, didn't fit.
- **v2** — corrected dims, board hung in a 6 mm gap. **Failed:** head captive in a
  round hole (couldn't insert) + snap-lips too tight for PLA.
- **v3** — slide-in tray with side grooves + a stadium head slot open at the mouth.
  **Failed:** board fit too tight to slide; head slot was open to its side.
- **v4** — looser slide-in tray + a **closed** stadium head hole (case replica,
  tilt-in-then-slide). **Superseded** before printing — see v5.
- **v5 (current)** — **SCREW-MOUNT, no sliding at all** (user: "vergiss alles mit
  sliding"). The board has **two ⌀2 mm mounting holes** → use them. The board
  screws onto **two ⌀3.5 mm standoffs** (M2 ⌀1.6 self-tap pilot) that hang from
  the top plate; the head pokes through a plain **round** hole; pins/wires hang
  off into the enclosure. Two screws fully constrain the board (X, Y, rotation);
  the standoff height sets the 6 mm gap (poke-out 1.5 mm, pin clearance 1.0 mm).

---

## Key geometry (v5)

| | Value |
|---|---|
| Test plate | 30 × 25 × 2.5 mm |
| Standoffs | ⌀3.5 × 6 mm tall, M2 ⌀1.6 pilot, at **x = −7.5, y = ±5** (10 mm apart, 2.5 mm from the no-pin edge) |
| Board fixing | 2× M2 self-tapping screws through the ⌀2 board holes into the pilots — **fastening method confirmed by user 2026-06-13** |
| Head hole | plain **round ⌀13.2** at (x = −1, y = 0), through the plate |
| Mount gap | 6 mm → head pokes out **1.5 mm**, pins clear plate by **1.0 mm** |

All driven by parameters at the top of the `.scad` (`pcb_*`, `head_*`, `mh_*`
mounting holes, `so_*` standoffs, `gap`, etc.). The poke-out / pin-clearance
trade-off is set by `gap`: poke_out = head_h − gap − ceil_t; pin_clear = gap − pin_h.

**Head ↔ standoff proximity (watch this):** the head hole rim and the standoff
bases are ~0.15 mm apart (centre distance 8.20 vs radii 6.6 + 1.75 = 8.35) —
they nearly touch because the real board crowds the head and both holes at the
same end. If they print merged/weak, reduce `head_clear` (e.g. 0.4) or `so_d`
(e.g. 3.0), or nudge `head_cx`.

---

## Print

PLA, 0.2 mm layer, 2 walls, 15% infill, **no supports**.
Orientation: **plate flat on bed, exterior (head-hole) face down, standoffs up.**
The round head hole bridges ⌀13.2 with no support — fine for PLA at 0.2 mm.

Regenerate:
```bash
cd models/tests
openscad -o ir_receiver_mount_test.stl ir_receiver_mount_test.scad
# preview (from repo root):
PYOPENGL_PLATFORM=egl .venv/bin/python ~/.claude/skills/parametric-3d-printing/preview.py \
  models/tests/ir_receiver_mount_test.stl models/tests/ir_receiver_mount_test_preview.png --views multi
```

---

## Open questions / pending user feedback

1. **Standoff spacing/position** — do the two standoffs line up with the board's
   holes (10 mm apart, 2.5 mm from the no-pin edge, centred on width)? (tune
   `mh_pitch`, `mh_edge`)
2. **Screw fit** — M2 self-tap is the chosen method (confirmed 2026-06-13); does
   the screw bite the ⌀1.6 pilot without stripping or splitting the standoff in
   PLA? (tune `so_pilot`, `so_d`)
3. **Standoff height / gap** — board sits level, head pokes ~1.5 mm, pins clear
   ~1 mm? (tune `gap`)
4. **Head centred?** Is the round hole centred on the head when the board is
   screwed down? `head_cx = −1` is inferred from "closer to the no-pin edge" —
   confirm/adjust. (tune `head_cx`, `head_clear`)
5. **Head/standoff merge** — did the hole rim and standoff bases print fused? If
   so, see the proximity note above.

---

## Next steps (after fit confirmed)

- Graft the plate + 2 standoffs + head hole into `electronics_enclosure.scad`
  top plate at the **front-centre between-LED cell ≈ (0, +50)** — a 25×25 cell
  bounded by LEDs at (±12.5, 37.5) and (±12.5, 62.5); nearest LED ~17.7 mm away,
  so the ⌀13.2 head hole + the two standoffs fit with margin. Confirm the
  standoff footprint (x = −7.5, y = ±5 relative to the head) clears LED
  bodies/leads at that cell before committing.
- Verify it clears the ESP32 (~+18, +15) and the USB-C board (back, Y ≈ −39.5).
- Firmware-side note already in `CLAUDE.md`; update the enclosure section there
  once the mount is integrated.

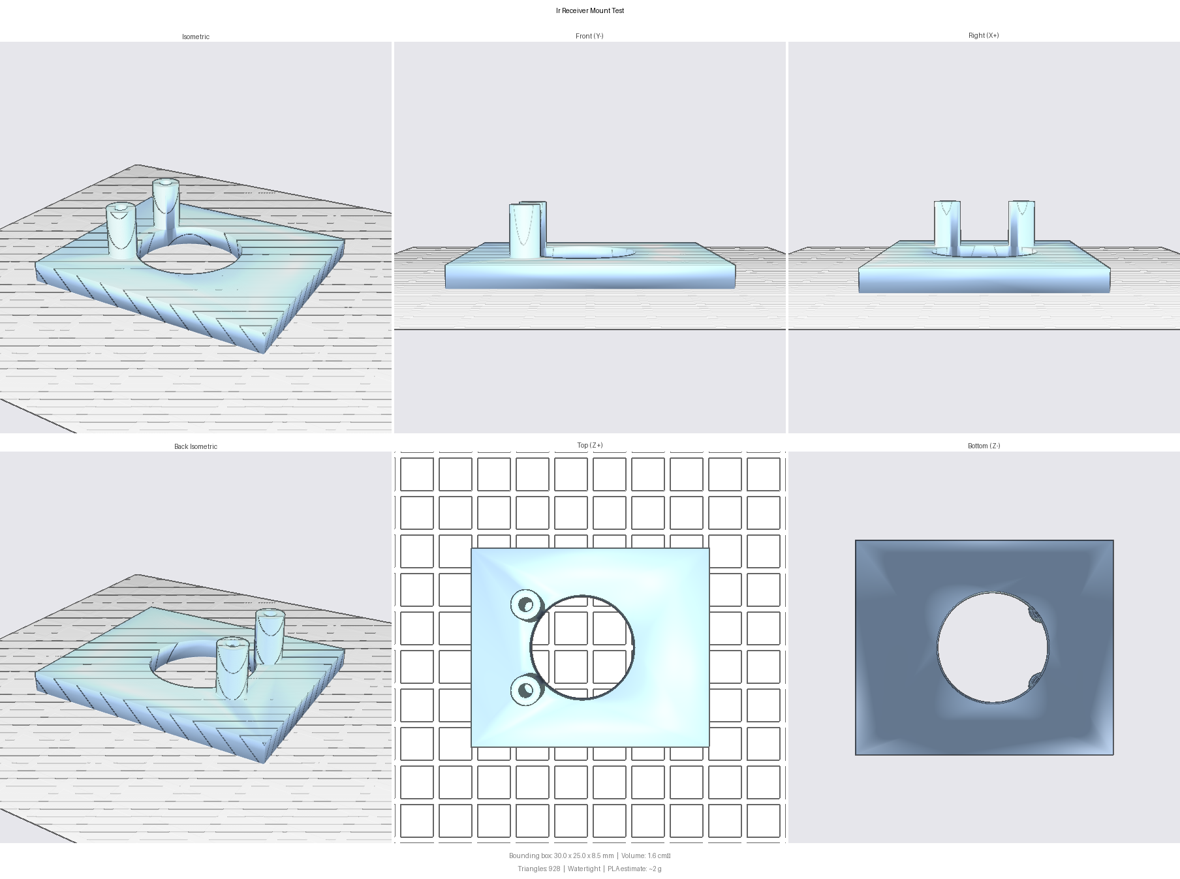
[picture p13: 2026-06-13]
models/tests/ir_receiver_mount_test_preview.png

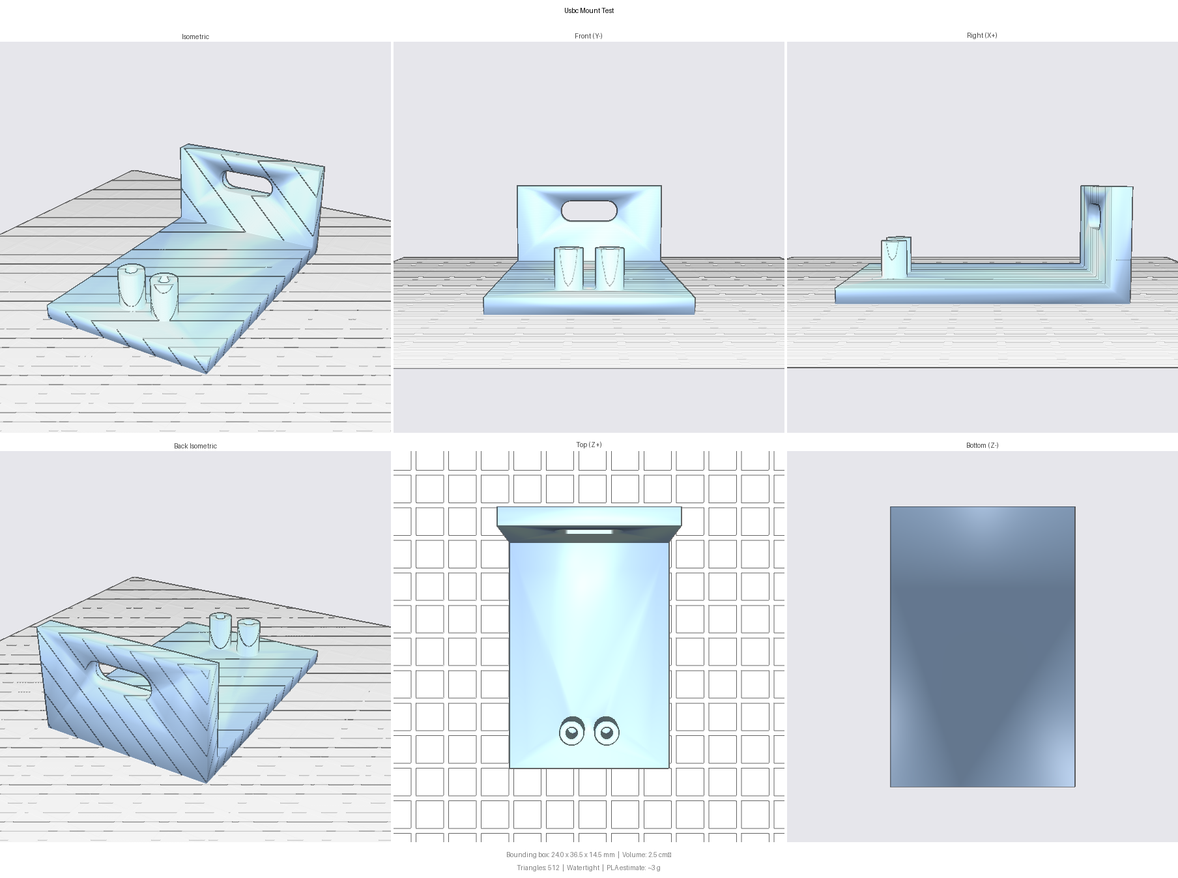
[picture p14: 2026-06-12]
models/tests/usbc_mount_test_preview.png

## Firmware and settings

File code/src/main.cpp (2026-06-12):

#include <Arduino.h>
#include <Preferences.h>
// Leave ALL protocol decoders enabled so any remote shows up in the serial log.
// Once the remote's protocol is confirmed, narrow with e.g. `#define DECODE_NEC` to save flash.
#include <IRremote.hpp>
#include "Cube.h"
#include "Text.h"
#include "modes/ModeWaves.h"
#include "modes/ModeRainbow.h"
#include "modes/ModeBreath.h"
#include "modes/ModeRipple.h"
#include "modes/ModeComet.h"
#include "modes/ModeSpiral.h"
#include "modes/ModePlane.h"
#include "modes/ModeSurface.h"
#include "modes/ModeRain.h"
#include "modes/ModeTetris.h"

#define DATA_PIN 14
#define CONTROL_BUTTON_PIN 33
#define BOOT_BUTTON_PIN 0
#define IR_RECEIVE_PIN 34

constexpr int INITIAL_MODE = 0;
constexpr uint32_t DEBOUNCE_MS = 50;

// Elegoo IR remote — NEC command bytes (watch the serial log to confirm for your unit)
constexpr uint8_t IR_POWER     = 0x45;  // power      -> blank / unblank the cube
constexpr uint8_t IR_VOL_UP    = 0x46;  // VOL+       -> brighter
constexpr uint8_t IR_FUNC_STOP = 0x47;  // FUNC/STOP  -> restart current mode
constexpr uint8_t IR_PREV      = 0x44;  // |<<        -> previous mode
constexpr uint8_t IR_PLAY      = 0x40;  // >||        -> pause / resume animation
constexpr uint8_t IR_NEXT      = 0x43;  // >>|        -> next mode
constexpr uint8_t IR_DOWN      = 0x07;  // arrow down -> previous mode
constexpr uint8_t IR_VOL_DOWN  = 0x15;  // VOL-       -> dimmer
constexpr uint8_t IR_UP        = 0x09;  // arrow up   -> next mode
constexpr uint8_t IR_EQ        = 0x19;  // EQ         -> factory reset (all settings to defaults)
constexpr uint8_t IR_ST_REPT   = 0x0D;  // ST/REPT    -> toggle auto-cycle
constexpr uint8_t IR_0         = 0x16;  // number keys -> jump straight to a mode
constexpr uint8_t IR_1         = 0x0C;
constexpr uint8_t IR_2         = 0x18;
constexpr uint8_t IR_3         = 0x5E;
constexpr uint8_t IR_4         = 0x08;
constexpr uint8_t IR_5         = 0x1C;
constexpr uint8_t IR_6         = 0x5A;
constexpr uint8_t IR_7         = 0x42;
constexpr uint8_t IR_8         = 0x52;
constexpr uint8_t IR_9         = 0x4A;

// Brightness limits (NeoPixel scale). Keep max sane: ~80 ≈ 4.1 A full-white on the ~5 A PD board.
constexpr uint8_t BRIGHT_MIN     = 5;
constexpr uint8_t BRIGHT_MAX     = 80;
constexpr uint8_t BRIGHT_STEP    = 10;
constexpr uint8_t BRIGHT_DEFAULT = 40;

constexpr uint32_t AUTO_CYCLE_MS = 15000;  // auto-advance interval when ST/REPT is on
constexpr uint32_t MULTI_DIGIT_MS = 1000;  // window to combine number keys into one mode number

constexpr float SPEED_MIN    = 0.25f;      // |<< / >>| scale the current mode's animation speed
constexpr float SPEED_MAX    = 4.0f;
constexpr float SPEED_FACTOR = 1.5f;       // multiply / divide per press

Cube cube(DATA_PIN);

ModeWaves modeWaves;
ModeRainbow modeRainbow;
ModeBreath modeBreath;
ModeRipple modeRipple;
ModeComet modeComet;
ModeSpiral modeSpiral;
ModePlane modePlane;
ModeSurface modeSurface;
ModeRain modeRain;
ModeTetris modeTetris;

Mode* modes[] = { &modeWaves,
                  &modeTetris, &modeRipple, &modeSpiral, &modeComet,
                  &modePlane, &modeSurface,
                  &modeRain, &modeRainbow, &modeBreath };
constexpr int NUM_MODES = sizeof(modes) / sizeof(modes[0]);

Preferences prefs;
TextScroll modeLabel;

int modeIndex = INITIAL_MODE;
Mode* currentMode = modes[INITIAL_MODE];
bool modePending = false;    // true while the mode name is scrolling

uint8_t brightness = BRIGHT_DEFAULT;
bool displayOn = true;       // false = blanked via the Power button
bool paused = false;         // true = animation frozen via Play/Pause
bool autoCycle = false;      // true = auto-advance through the modes
uint32_t lastCycleMs = 0;    // last time the auto-cycle (or a mode change) fired

int typedNumber = 0;         // number-key entry so far (1-based mode #, 0 = none pending)
uint32_t lastDigitMs = 0;    // last number-key press, for the multi-digit window

float speed = 1.0f;          // animation speed multiplier (|<< slower, >>| faster)
uint32_t modeClock = 0;      // speed-scaled virtual time fed to the current mode's update()
uint32_t lastRealMs = 0;     // real millis() at the previous loop, for the clock delta
float clockFrac = 0.0f;      // sub-ms remainder carried between frames (keeps slow speeds smooth)

struct Button {
    int pin;
    bool lastState;
    bool pending;
    uint32_t pendingMs;
};

Button controlButton = { CONTROL_BUTTON_PIN, HIGH, false, 0 };
Button bootButton = { BOOT_BUTTON_PIN, HIGH, false, 0 };

// Persist every user setting to NVS (setMode also calls this on manual mode changes).
void saveSettings() {
    prefs.putInt("mode", modeIndex);
    prefs.putUChar("bright", brightness);
    prefs.putFloat("speed", speed);
    prefs.putBool("paused", paused);
    prefs.putBool("display", displayOn);
    prefs.putBool("cycle", autoCycle);
}

void applyBrightness(int value) {
    if (value < BRIGHT_MIN) value = BRIGHT_MIN;
    if (value > BRIGHT_MAX) value = BRIGHT_MAX;
    brightness = (uint8_t)value;
    cube.setBrightness(brightness);
    cube.show();   // re-scale the current frame so the change shows immediately
    saveSettings();
    Serial.printf("brightness -> %d\n", brightness);
}

void changeSpeed(float factor) {
    speed *= factor;
    if (speed < SPEED_MIN) speed = SPEED_MIN;
    if (speed > SPEED_MAX) speed = SPEED_MAX;
    saveSettings();
    Serial.printf("speed -> %.2fx\n", speed);
}

void setMode(int index, bool manual = true) {
    currentMode->onExit(cube);
    modeIndex = ((index % NUM_MODES) + NUM_MODES) % NUM_MODES;  // wrap; safe for negatives
    currentMode = modes[modeIndex];
    displayOn = true;          // any mode change wakes the display...
    paused = false;            // ...and resumes animation
    if (manual) autoCycle = false;  // a manual mode change stops auto-cycling
    lastCycleMs = millis();    // restart the auto-cycle clock
    typedNumber = 0;           // end any multi-digit entry (enterDigit re-sets it afterwards)
    if (manual) saveSettings();                   // persist mode + the reset flags
    else        prefs.putInt("mode", modeIndex);  // auto-cycle: only the mode changed
    // show the mode label; the mode itself starts once it finishes.
    // give each mode its own hue, evenly spread around the colour wheel.
    char label[8];
    snprintf(label, sizeof(label), "%d", modeIndex + 1);  // 1-based for display
    uint16_t hue = (uint32_t)modeIndex * 65536UL / NUM_MODES;
    modeLabel.start(label, millis(), Cube::colorHSV(hue));
    modePending = true;
}

// A number key was pressed. Combine digits typed within MULTI_DIGIT_MS into one mode number
// (so "1" then "0" -> mode 10). If the combined number has no matching mode, fall back to the
// single digit just pressed (so "4" then "2" -> mode 2, since there is no mode 42).
void enterDigit(int digit, uint32_t now) {
    int candidate = digit;
    if (typedNumber > 0 && now - lastDigitMs <= MULTI_DIGIT_MS) {
        int combined = typedNumber * 10 + digit;
        if (combined >= 1 && combined <= NUM_MODES) {
            candidate = combined;     // extend the current number
        }                             // else: no such mode -> keep just this digit
    }
    lastDigitMs = now;
    if (candidate >= 1 && candidate <= NUM_MODES) {
        setMode(candidate - 1);       // typed number is 1-based; mode index is 0-based
        typedNumber = candidate;      // setMode cleared it; restore so the next digit can extend
    } else {
        typedNumber = 0;              // a lone "0" has no mode — ignore and reset entry
    }
}

// EQ button: wipe stored settings and return everything to defaults.
void factoryReset() {
    Serial.println("FACTORY RESET -> defaults");
    prefs.clear();                 // erase the saved namespace
    brightness = BRIGHT_DEFAULT;
    speed      = 1.0f;
    cube.setBrightness(brightness);
    setMode(INITIAL_MODE);         // resets the flags and re-persists all defaults
}

// Map one decoded remote command to an action. Repeat frames are filtered upstream.
void handleIrCommand(uint16_t cmd, uint32_t now) {
    switch (cmd) {
        // mode navigation (arrows; also the BOOT button and number keys)
        case IR_UP:   setMode(modeIndex + 1); break;
        case IR_DOWN: setMode(modeIndex - 1); break;

        // animation speed of the current mode (skip buttons)
        case IR_NEXT: changeSpeed(SPEED_FACTOR);        break;  // >>|  faster
        case IR_PREV: changeSpeed(1.0f / SPEED_FACTOR); break;  // |<<  slower

        // number keys -> select a mode by number (multi-digit; "1"+"0" = mode 10, see enterDigit)
        case IR_1: enterDigit(1, now); break;
        case IR_2: enterDigit(2, now); break;
        case IR_3: enterDigit(3, now); break;
        case IR_4: enterDigit(4, now); break;
        case IR_5: enterDigit(5, now); break;
        case IR_6: enterDigit(6, now); break;
        case IR_7: enterDigit(7, now); break;
        case IR_8: enterDigit(8, now); break;
        case IR_9: enterDigit(9, now); break;
        case IR_0: enterDigit(0, now); break;

        // brightness
        case IR_VOL_UP:   applyBrightness(brightness + BRIGHT_STEP); break;
        case IR_VOL_DOWN: applyBrightness(brightness - BRIGHT_STEP); break;
        case IR_EQ:       factoryReset(); break;   // wipe all settings -> defaults

        // power / playback
        case IR_POWER:
            displayOn = !displayOn;
            if (!displayOn) { cube.clear(); cube.show(); }
            saveSettings();
            Serial.printf("display %s\n", displayOn ? "ON" : "OFF");
            break;
        case IR_PLAY:
            paused = !paused;
            saveSettings();
            Serial.println(paused ? "paused" : "resumed");
            break;
        case IR_FUNC_STOP:
            setMode(modeIndex);   // restart the current mode (replays its label)
            break;
        case IR_ST_REPT:
            autoCycle = !autoCycle;
            lastCycleMs = now;
            saveSettings();
            Serial.printf("auto-cycle %s\n", autoCycle ? "ON" : "OFF");
            break;

        default:
            Serial.printf("unmapped IR cmd 0x%02X\n", cmd);
            break;
    }
}

bool wasPressed(Button& btn, uint32_t now) {
    bool state = digitalRead(btn.pin);
    if (state != btn.lastState) {
        btn.lastState = state;
        btn.pending = true;
        btn.pendingMs = now;
    }
    if (btn.pending && (now - btn.pendingMs >= DEBOUNCE_MS)) {
        btn.pending = false;
        if (btn.lastState == LOW) {
            return true;
        }
    }
    return false;
}

void setup() {
    Serial.begin(115200);
    Serial.println("LED Cube boot OK");
    pinMode(CONTROL_BUTTON_PIN, INPUT_PULLUP);
    pinMode(BOOT_BUTTON_PIN, INPUT_PULLUP);
    controlButton.lastState = digitalRead(CONTROL_BUTTON_PIN);
    bootButton.lastState = digitalRead(BOOT_BUTTON_PIN);
    IrReceiver.begin(IR_RECEIVE_PIN);  // no on-board LED feedback
    Serial.printf("IR receiver started on GPIO%d, active protocols: ", IR_RECEIVE_PIN);
    IrReceiver.printActiveIRProtocols(&Serial);
    Serial.println();
    cube.begin();

    // restore all saved settings (defaults match the global initialisers)
    bool prefsOk  = prefs.begin("led-cube", false);
    int savedMode = prefs.getInt("mode", INITIAL_MODE);
    brightness    = prefs.getUChar("bright", BRIGHT_DEFAULT);
    speed         = prefs.getFloat("speed", 1.0f);
    bool sPaused  = prefs.getBool("paused", false);
    bool sDisplay = prefs.getBool("display", true);
    bool sCycle   = prefs.getBool("cycle", false);
    if (brightness < BRIGHT_MIN) brightness = BRIGHT_MIN;
    if (brightness > BRIGHT_MAX) brightness = BRIGHT_MAX;
    if (speed < SPEED_MIN) speed = SPEED_MIN;
    if (speed > SPEED_MAX) speed = SPEED_MAX;
    cube.setBrightness(brightness);
    Serial.printf("prefs %s | mode %d bright %d speed %.2f paused %d display %d cycle %d\n",
                  prefsOk ? "ok" : "FAILED", savedMode, brightness, speed, sPaused, sDisplay, sCycle);

    setMode(savedMode, false);   // restore mode without resetting/over-persisting the flags
    displayOn = sDisplay;        // ...then re-apply the saved flags that setMode forced
    paused    = sPaused;
    autoCycle = sCycle;
    saveSettings();              // persist the fully-restored state
    lastRealMs = millis();
}

void loop() {
    uint32_t now = millis();
    uint32_t delta = now - lastRealMs;   // real time elapsed since the previous loop
    lastRealMs = now;

    if (wasPressed(bootButton, now)) {
        setMode(modeIndex + 1);
        Serial.printf("mode -> %d\n", modeIndex);
    }

    if (IrReceiver.decode()) {
        // DEBUG: dump every frame — protocol, address, command, raw data, repeat flag.
        // Read the Command=0x.. value for your button and set the matching IR_* constant.
        IrReceiver.printIRResultShort(&Serial);

        IRData& ir = IrReceiver.decodedIRData;
        // ignore the auto-repeat frames sent while a button is held down
        if (!(ir.flags & IRDATA_FLAGS_IS_REPEAT)) {
            handleIrCommand(ir.command, now);
        }
        IrReceiver.resume();  // ready for the next frame
    }

    // auto-advance through the modes when ST/REPT is on
    if (autoCycle && displayOn && !paused && !modePending && now - lastCycleMs >= AUTO_CYCLE_MS) {
        setMode(modeIndex + 1, false);   // false = automatic, so it doesn't cancel auto-cycle
    }

    // blanked via Power — keep the cube dark, skip all rendering
    if (!displayOn) {
        return;
    }

    // while the mode name is scrolling, hold off starting the mode
    if (modePending) {
        modeLabel.update(cube, now);
        if (modeLabel.active()) {
            return;
        }
        currentMode->onEnter(cube);
        modePending = false;
    }

    // frozen via Play/Pause — leave the last frame on the cube
    if (paused) {
        return;
    }

    // advance the speed-scaled clock now that we know a frame will render, so pausing,
    // blanking, or a label scroll never makes the animation jump when it resumes.
    float advance = (float)delta * speed + clockFrac;
    uint32_t whole = (uint32_t)advance;
    clockFrac = advance - (float)whole;
    modeClock += whole;
    currentMode->update(cube, modeClock);
}

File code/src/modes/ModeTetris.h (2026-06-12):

#pragma once
#include "../Mode.h"
#include <Arduino.h>
#include <math.h>
#include <string.h>

// ModeTetris — a self-playing 3D Tetris ("Tetris Effect" vibe) for the 6x6x6 cube.
//
// Legit Tetris, played by the cube itself. The seven tetrominoes fall in their
// iconic colours (I-cyan, O-yellow, T-purple, S-green, Z-red, J-blue, L-orange),
// rotate in FULL 3D (they can lie flat OR stand upright), and land by real
// gravity/collision. Full 6x6 layers are NOT cleared the instant they fill — the
// stack builds up until several full layers have stacked (an organic per-round
// mix of 1/2/3/4, weighted to 3), then they all flash white together and the
// stack above collapses into the gap. A safety clear fires if the stack nears
// the ceiling with full layers waiting, so it rarely tops out. No layer is ever
// force-cleared before it is genuinely, completely full.
//
// A greedy bot places each piece using an El-Tetris-style score: take real
// clears, never bury holes, keep the stack low and flat. Standing pieces let it
// fill narrow wells, so it survives a long time. If it is ever genuinely boxed
// in — no orientation of the next piece fits under the ceiling — that is a real
// top-out: it plays a short game-over dissolve and starts a fresh game (the
// rules, not a cheat). A slow brightness wave breathes over the settled stack.
//
// NB: phase enumerators are PH_-prefixed on purpose — Arduino #defines FALLING /
// RISING / CHANGE as interrupt-edge macros that would clobber a bare `FALLING`.
class ModeTetris : public Mode {
public:
    explicit ModeTetris(float fallPerFrame = 0.18f,
                        uint32_t frameMs = 30,
                        float shimmerSpeed = 0.010f)
        : _fallPerFrame(fallPerFrame), _frameMs(frameMs),
          _shimmerSpeed(shimmerSpeed), _lastMs(0), _shimmer(0.0f) {
    }

    void onEnter(Cube& cube) override {
        generateOrients();
        resetGrid();
        _shimmer = 0.0f;
        _clearTarget = pickClearTarget();
        _bagPos  = NUM_PIECES;   // force a fresh shuffle on the first spawn
        _phase   = PH_SPAWN;
        _phaseT  = 0;
        _lastMs  = 0;
        cube.clear();
        cube.show();
    }

    void update(Cube& cube, uint32_t ms) override {
        if (ms - _lastMs < _frameMs) {
            return;
        }
        _lastMs = ms;
        _shimmer += _shimmerSpeed;
        if (_shimmer > 1000.0f) _shimmer -= 1000.0f;

        switch (_phase) {
            case PH_SPAWN:    stepSpawn();    break;
            case PH_FALLING:  stepFalling();  break;
            case PH_LOCKED:   stepLocked();   break;
            case PH_FLASH:    stepFlash();    break;
            case PH_COLLAPSE: stepCollapse(); break;
            case PH_GAMEOVER: stepGameOver(); break;
        }
        render(cube);
        cube.show();
    }

private:
    static constexpr int NUM_PIECES  = 7;
    static constexpr int PLANE_CELLS = CUBE_X * CUBE_Z;
    static constexpr int MAX_ORI     = 24;   // max distinct 3D rotations of a tetromino

    enum Phase { PH_SPAWN, PH_FALLING, PH_LOCKED, PH_FLASH, PH_COLLAPSE, PH_GAMEOVER };

    static constexpr uint32_t LOCK_MS     = 100;
    static constexpr uint32_t FLASH_MS    = 170;
    static constexpr uint32_t COLLAPSE_MS = 150;
    static constexpr uint32_t GAMEOVER_MS = 1100;

    // a normalised orientation: 4 cells (offsets) + per-axis extents
    struct Orient { int8_t c[4][3]; uint8_t ex, ey, ez; };

    // iconic Tetris colours, packed as Adafruit Color(): (r<<16)|(g<<8)|b
    static uint32_t pieceColor(uint8_t id) {
        static const uint32_t COLORS[NUM_PIECES] = {
            0x00FFFFu, 0xFFFF00u, 0xA000F0u, 0x00FF00u, 0xFF0000u, 0x0000FFu, 0xFF8C00u
        };
        return COLORS[(id - 1) % NUM_PIECES];
    }

    // ── 3D orientation generation ───────────────────────────────────────
    // 90° right-handed rotations about each axis.
    static void rotX(int c[3]) { int y = c[1], z = c[2]; c[1] = -z; c[2] =  y; }
    static void rotY(int c[3]) { int x = c[0], z = c[2]; c[0] =  z; c[2] = -x; }
    static void rotZ(int c[3]) { int x = c[0], y = c[1]; c[0] = -y; c[1] =  x; }

    static void normalize(int s[4][3]) {
        int mnx = s[0][0], mny = s[0][1], mnz = s[0][2];
        for (int i = 1; i < 4; i++) {
            if (s[i][0] < mnx) mnx = s[i][0];
            if (s[i][1] < mny) mny = s[i][1];
            if (s[i][2] < mnz) mnz = s[i][2];
        }
        for (int i = 0; i < 4; i++) { s[i][0] -= mnx; s[i][1] -= mny; s[i][2] -= mnz; }
    }

    // order-independent key for a normalised shape (coords 0..3 → 2 bits each)
    static uint32_t shapeKey(const int s[4][3]) {
        int v[4];
        for (int i = 0; i < 4; i++) v[i] = (s[i][0] << 4) | (s[i][1] << 2) | s[i][2];
        for (int a = 0; a < 3; a++)
            for (int b = 0; b < 3 - a; b++)
                if (v[b] > v[b + 1]) { int t = v[b]; v[b] = v[b + 1]; v[b + 1] = t; }
        return ((uint32_t)v[0] << 18) | ((uint32_t)v[1] << 12)
             | ((uint32_t)v[2] << 6)  | (uint32_t)v[3];
    }

    // BFS the rotation group from each canonical shape, deduping by key.
    void generateOrients() {
        static const int8_t BASE[NUM_PIECES][4][3] = {
            {{0,0,0},{1,0,0},{2,0,0},{3,0,0}},  // I
            {{0,0,0},{1,0,0},{0,1,0},{1,1,0}},  // O
            {{0,0,0},{1,0,0},{2,0,0},{1,1,0}},  // T
            {{1,0,0},{2,0,0},{0,1,0},{1,1,0}},  // S
            {{0,0,0},{1,0,0},{1,1,0},{2,1,0}},  // Z
            {{0,0,0},{1,0,0},{2,0,0},{0,1,0}},  // J
            {{0,0,0},{1,0,0},{2,0,0},{2,1,0}},  // L
        };
        for (int t = 0; t < NUM_PIECES; t++) {
            _norient[t] = 0;
            uint32_t keys[MAX_ORI];
            int nk = 0;
            int base[4][3];
            for (int i = 0; i < 4; i++) {
                base[i][0] = BASE[t][i][0]; base[i][1] = BASE[t][i][1]; base[i][2] = BASE[t][i][2];
            }
            normalize(base);
            addOrient(t, base, keys, nk);
            for (int qi = 0; qi < _norient[t]; qi++) {       // closure over the orientation list
                for (int r = 0; r < 3; r++) {
                    int s[4][3];
                    for (int i = 0; i < 4; i++) {
                        s[i][0] = _orient[t][qi].c[i][0];
                        s[i][1] = _orient[t][qi].c[i][1];
                        s[i][2] = _orient[t][qi].c[i][2];
                    }
                    for (int i = 0; i < 4; i++) {
                        if (r == 0) rotX(s[i]); else if (r == 1) rotY(s[i]); else rotZ(s[i]);
                    }
                    normalize(s);
                    addOrient(t, s, keys, nk);
                }
            }
        }
    }
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

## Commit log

2026-06-12 Restructure repo to include parent project folder
    Move the git root up from code/ to the project root so the repository
    now tracks the full project: firmware (code/), 3D models (models/),
    design docs (docs/) and BUILD.md/CLAUDE.md. Firmware files retain history
    via rename detection. Environment state (.venv, .claude, .remember) is
    gitignored.
    [electronics_enclosure.scad, electronics_enclosure_body.stl, electronics_enclosure_lid.stl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]
2026-06-12 Add README; organize models into subfolders, drop dev stages
    - Add a project README (with a note that the firmware is vibecoded).
    - Group model files into per-part subfolders: layer_jig/, electronics_enclosure/,
    led_pin_bender/, tests/.
    - Remove development-stage artifacts (phase1/phase2 STLs + previews), the stale
    CadQuery layer_jig.py prototype, and the duplicate preview_body.png.
    - Regenerate led_pin_bender preview from its current .scad.
    [electronics_enclosure.scad, electronics_enclosure_body.stl, electronics_enclosure_lid.stl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]
2026-06-12 Update BUILD.md to remove power cap details
    Removed obsolete power cap information from the documentation.
2026-06-12 usbc test
    [electronics_enclosure.scad, electronics_enclosure_body.stl, usbc_mount_test.scad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]
2026-06-12 remote control
    [ir_receiver_mount_test.scad, ir_receiver_mount_test.stl]
2026-06-12 Add IR remote control for the LED cube
    Wire up an Elegoo NEC IR remote (VS1838B receiver on GPIO34) to drive
    the cube, with all settings persisted to NVS:
    - Full remote mapping in handleIrCommand(): arrows = next/prev mode,
    number keys = direct mode select (multi-digit, "1"+"0" = mode 10),
    skip buttons = animation speed, VOL+/- = brightness, EQ = factory
    reset, Play = pause, Power = blank, FUNC/STOP = restart, ST/REPT =
    auto-cycle (cancelled by any manual mode change).
    - Modes run on a speed-scaled virtual clock (modeClock) instead of
    millis(), so speed/pause are global with no per-mode changes.
    - saveSettings() persists mode, brightness, speed, pause, blank, and
    auto-cycle; set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
    [main.cpp]
2026-06-12 test model
    [ir_receiver_mount_test.scad, ir_receiver_mount_test.stl]
